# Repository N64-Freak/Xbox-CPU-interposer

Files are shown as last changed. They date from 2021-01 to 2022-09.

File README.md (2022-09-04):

# Xbox-CPU-interposer
This is the documentation for the 1,4ghz CPU upgrade for the original Xbox.

## ---WARNING---
* You should be comfortable with BGA rework or at least know how to work with BGA components.
* And it should also not be your first time soldering small smd components!

## Compatibility:
It's compatible with every motherboard revision of the original Xbox but you want a rev1.0 - rev1.4 for a couple reasons:
* Rev 1.5 doesn't exist!

Update: As the rev1.6 can now officially be upgraded to 128mb ram there's no real reason not to use it!
Only thing to mention is that the install is a little more complex as one electrolytic capacitor has to be moved.

## Useability
The CPU upgraded boards have a LOT more processing power compared to the stock 733Mhz CPU of the original xbox.  
Downside of this is that retail games need to be patched to run at normal speeds again.  
Some games need to be patched others don't.
The Patching Software is found in the "Software" tab.

## Why would you want such a console?
* Less slowdowns in retail games
* More processing power for emulation
* Not everyone has one of them!
* It's like the ultimate mod you can do to an Xbox

## Now you want to build one yourself?
If you want to build one yourself hit me up and i can offer you one or a couple of the interposer boards.  
I do have stock in Germany and the US so shipping won't take long if you are in the US.  
Contact me at N64freak@gmx.de

Prices are:
- 1 interposer board: 15€ +shipping 
- 5 interposer boards: 50€ +shipping

If you want a custom amount just message me.

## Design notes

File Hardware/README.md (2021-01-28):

# Required Tools and parts
For the upgrade you should have good tools to suceed. Specially good soldering equipment and a steady hand!
You will need:
* BGA Rework station (alternatively a Hot-air Station and a preheater)
* Temperature controlled soldering iron
* A set of tweezers to install the smd components
* Solder paste and dispenser
* Solder wick to clean the board after removing the original CPU
* And of course flux!

## Choosing a processor
If you do the upgrade it is recommended to choose the 1400Mhz version of the processor.  
But because they get expensiver i recommend to use a 1000Mhz or 1200Mhz CPU to practice and continue with the expensiver CPU once you succeeded.  
  
Here's a list of tested CPUs:
| SSPEC Number | Clock speed | Cache |  
| --- | --- | --- |
| SL5XL | 1400Mhz |  512Kb |  
| SL6BY | 1400Mhz |  512Kb |  
| SL5VX | 1333Mhz |  256Kb |  
| SL6BZ | 1333Mhz |  256Kb |  
| SL5LW | 1266Mhz |  512Kb |  
| SL5VX | 1200Mhz |  256Kb |  
| ... | ... | ... |  
  
Basically any Socket 370 Pentium 3 with 133Mhz FSB will work.  
The tualatin core CPUs are recommended as the heatspreader allows for easier heatsink attachment and they have 512kKB Level 2 Cache!

## SMD Components
You can buy the components from the vendor of your choice. 
NOTE: If you have a Rev1.2-1.4 you need to bu an extra 1.5Kohm 0603 resistor to set the CPU core voltage!  

| Reference | Qty | Description | Part Number | Manufacturer | Digikey part number |  
| --- | --- | --- | --- | --- | --- |
| R6 | 1 | Res 0Ohm, 0603 | RC0603FR-070RL | Yageo | 311-0.0HRCT-ND |  
| RN1 | 1 | Res 1KOhm, 0603x4 |  |  |  |  
| R2, R8 | 2 | Res 1KOhm, 0603 | ESR03EZPJ102 | Rohm | RHM1.0KDCT-ND |  
| C5 | 1 | Cap 1nF, 0603 | C0603C102K4RECAUTO | Kemet | 399-17878-1-ND |  
| C45 | 1 | Cap 1uF, 0603 | CL10A105KA8NNNC | Samsung | 1276-1102-1-ND |  
| C14-C17,C19,C20,C23,C33,C34,C37,C38,C42 | 12 | Cap 4.7uF, 0805 | CL21A475KAQNNNE | Samsung | 1276-1244-1-ND |  
| C3,C4 | 2 | Cap 10pF, 0603 | 06035A100JAT2A | AVX | 478-1163-1-ND |  
| C7 | 1 | Cap 10uF, 0805 | CL21A106KOQNNNG | Samsung | 1276-6455-1-ND |  
| R5 | 1 | Res 15Ohm, 0603 | RNCP0603FTD15R0 | Stackpole | RNCP0603FTD15R0CT-ND |  
| R1 | 1 | Res 33Ohm, 0603 | CRGCQ0603J33R | TE | A130082CT-ND |  
| R7 | 1 | Res 100Ohm, 0603 | RT0603DRD07100RL | Yageo | 311-100DCT-ND  |  
| C1,C2,C6,C8-C13,C18,C21,C22,C24-C32,C35,C36,C39-C41,C43,C44,C46 | 29 | Cap 100nF, 0603 | CL10B104KB8NNNL | Samsung | 1276-CL10B104KB8NNNLCT-ND |  
| R3 | 1 | Res 330Ohm, 0603 | RC0603JR-07330RL | Yageo | 311-330GRCT-ND |  
| R4 | 1 | Res 470Ohm, 0603 | RC0603JR-07470RL | Yageo | 311-470GRCT-ND  |  
| D1 | 1 | LED Green, 0603 | LTST-C191KGKT | Lite-On | 160-1446-1-ND |  
| U2 | 1 | IC NC7SZ32, SOT23-5 | NC7SZ32M5X | ON-Semiconductor | NC7SZ32M5XCT-ND |  
| U1 | 1 | IC NC7WZ07, SC70 | NC7WZ07P6X | ON-Semiconductor | NC7WZ07P6XCT-ND |  
| OSC1 | 1 | OSC SG3030B | SG-3030JC 32.7680KB0: ROHS | Epson | SER4329CT-ND |  
| Con1 | 1 | JST 2pin SMD connector | JST-PH-2P-SMD | JST | --- |  
| R2E8 | 1 | Res 1.5Kohm, 0603 |  RC0603FR-071K5L  | Yageo |  311-1.50KHRCT-ND  |  

## Starting the install
First thing to do is reball the CPU Adapter. You need The 0.76mm leaded solder balls, flux and the reball stecil.  
Not going into details how to reball such a pcb here. You should be able to find instructional videos for it on youtube.  
  
<p align="center">
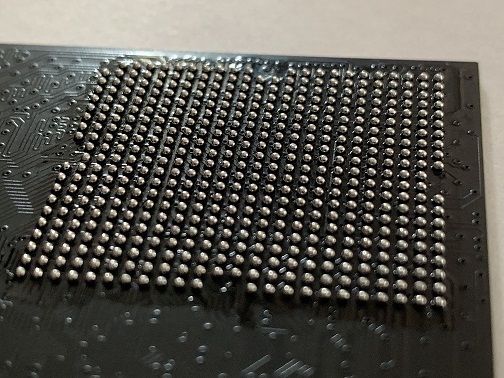
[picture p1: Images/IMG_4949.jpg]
  
</p> 

## Remove the original CPU
First thing to do on the motherboard is to fire up your bga rework station and remove the original CPU.  
Clean the remaining solder off the motherboard using solder wick and flux. After a cleanup you should have a nice and tidy looking board.
The result should look like this:  
  
<p align="center">
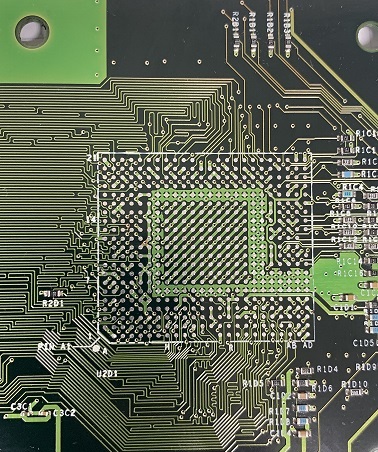
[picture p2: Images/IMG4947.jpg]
  
</p> 

## Setting the CPU core voltage
As the new CPU is running at a lower core voltage it has to be adjusted.  
---Don't forget about this step or you CPU might get damaged on the first startup!---  
Only a few changes have to be done to the resistors on the xbox console. Choose the correct image for the revision of your console.  
  
<p align="center">
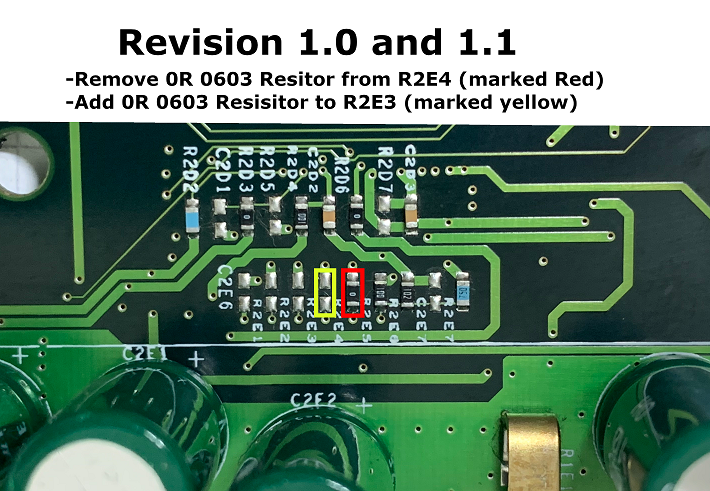
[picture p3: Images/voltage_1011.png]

</p> 
<p align="center">
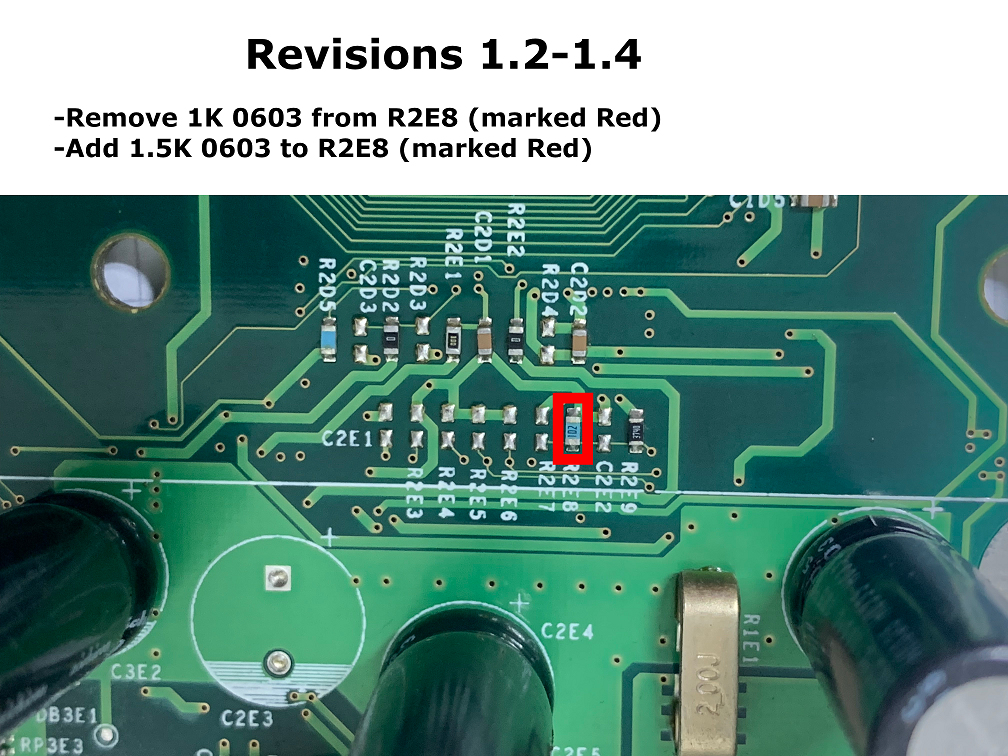
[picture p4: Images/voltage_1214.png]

</p> 

## Installing the Adapter
Next step is firing up your bga rework station again and solder in the CPU interposer board.  
Not much info here as you should know how to operate your rework station.  

<p align="center">
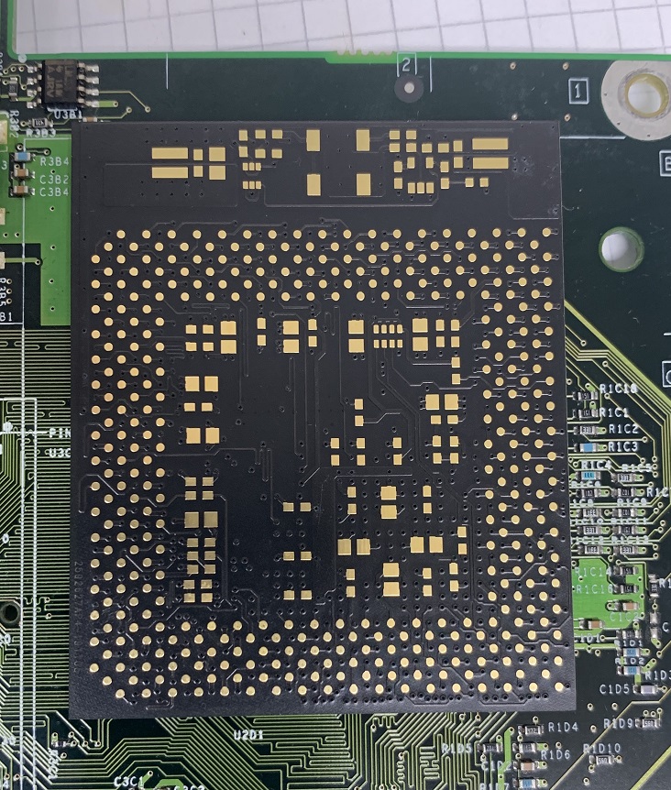
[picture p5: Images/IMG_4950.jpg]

</p> 

## Installing the SMD components
With the Adapter soldered on it's time to install all the smd components from the BOM above.  
You can install all off them at once or just the parts that will be below the cpu once installed.  
That's up to you!

## Install the CPU
Now on to the most important step of soldering the CPU itself. Get your solder paste out and add a drop to every single of the 370 solder pad for the CPU.  
Then position the CPU on there and get back to your bga rework station and get it soldered down.  
  
Note: Once the CPU is installed you can test the motherboard!  
  
When done it should look like this:  
<p align="center">
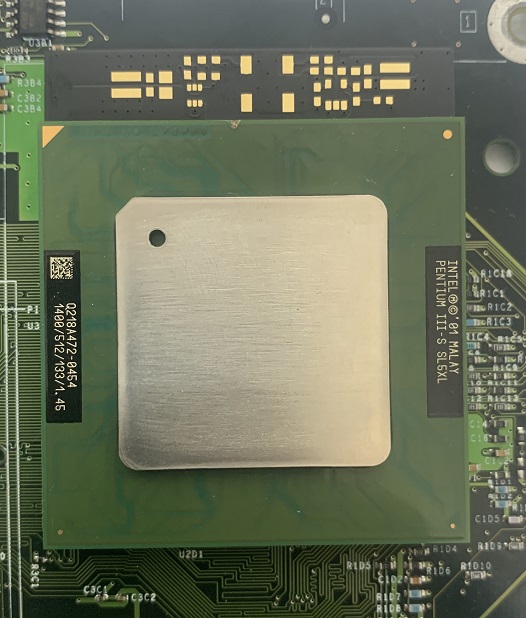
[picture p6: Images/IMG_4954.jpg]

</p> 

## Connecting power to the Adapter
The performance reduction circuit needs external power to work which has to be fed in externally.   Therefore 2 additional wires need to be attached to the cpu adapter.  
Connect the wires between the marked points and the system will be able to reduce the power to 50% of the maximum performance.  
  
Note: The system will NOT underclock the cpu.  
The cpu speed in XBMC will allways show the true clockspeed of 1400MHz!

<p align="center">
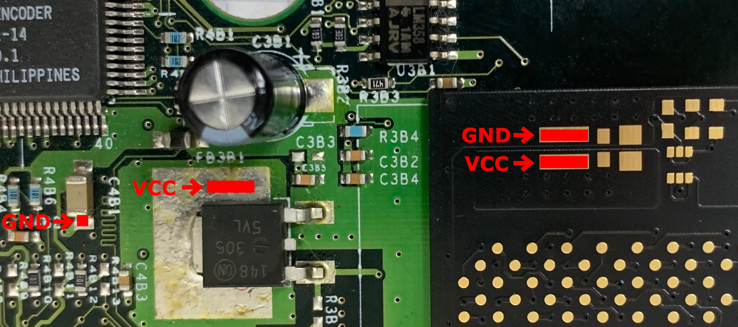
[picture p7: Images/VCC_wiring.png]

</p> 

## Common errors
If your system doesn’t boot up there is a problem with most likely either a component or your soldering.  
The most common error would be the FRAG which means flashing red and green.  
The system restarts 2 times and then flashes red and green.  
This error indicates a general hardware problem and as we just replaced the cpu you can take a guess which component it is.  
  
Reasons could be:  
-Defective CPU  
-Wrong cpu core voltage setting  
-Cold solder joint between adapter and motherboard or cpu and adapter  
  
Another error is the console flashing orange with the fans turned up to 100% instantly after power on.  
This error is a problem with either a defective cpu or a cold solder joint on the address or data lines of the cpu.  
To summarize it all one could say if it doesn’t boot up at the first try your chances are slim to get the console to work.  
The best you can do is inspect the solder points and rework any that look dodgy or are visually not connected.

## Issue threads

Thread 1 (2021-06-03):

feedback resistor value for CPU core regulator for mainboard rev 1.2 - 1.4  wrong

maximus64, 2021-06-03:
I'm in process of upgrade my CPU and after replacing R2E8 to 1.5K, the output voltage still measure around ~1.55V instead of 1.45V that the CPU want. I think the resistor value feedback network mention the the manual is wrong.

SC2688 datasheet mention the reference voltage is 1.25V
So base on my calculation with 1.5K resistor:
(1.25v)(1.5K + 379)/(1.5K) = 1.566V

This is too much for the CPU since spec is 1.45V. If we want 1.45V output I think the resistor should be ~2.4K (2368 ohm to be exact)

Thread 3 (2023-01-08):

socket CPU

Vitamin-X, 2023-01-08:
do you think its a easy to add an socket to that construction ? so you can change the CPU and got a cooler mount with it.

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

Grzegorz-Rey, 2024-07-17:
I came with similar idea to take a regular PGA370 from boards like above and design new PCB that match 4 holes existed on board that keep the plastic cover around cpu/xgpu. Then design a ribbon flex cable that can be soldered in place of old cpu and new board.
By that way, it should be possible to make these types of mods without a BGA station and simply using the usual soldering technique.

hetii, 2024-07-17:
I came with similar idea to take a regular PGA370 from boards like above and design new PCB that match 4 holes existed on board that keep the plastic cover around cpu/xgpu.
Then design a ribbon flex cable that can be soldered in place of old cpu and new board.

By that way, it should be possible to make these types of mods without a BGA station and simply by using the usual soldering technique.

Vitamin-X, 2024-07-20:
so you will solder a wire to each of the pins? or you mean a special custom flex pcb that perfectly fits the old CPU socket?
